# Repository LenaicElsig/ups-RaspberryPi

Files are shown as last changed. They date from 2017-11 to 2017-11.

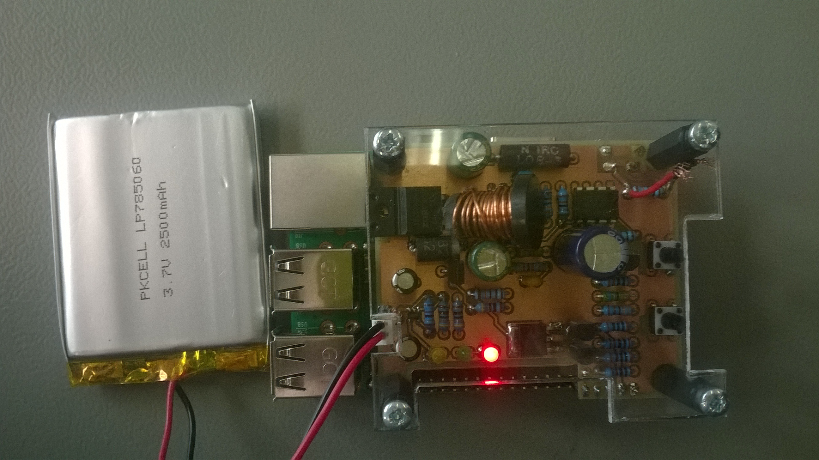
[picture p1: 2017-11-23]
WP_20171013_008.jpg

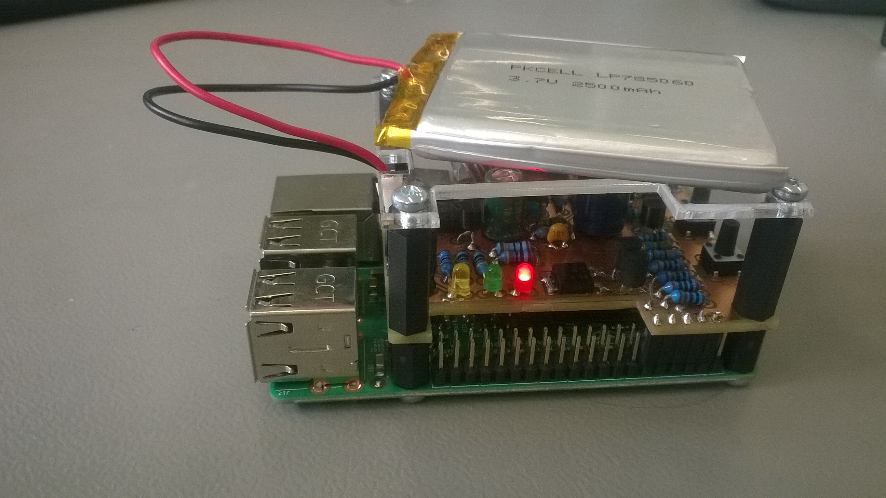
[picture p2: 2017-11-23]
WP_20171013_006.jpg

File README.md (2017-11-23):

# ups-RaspberryPi
Uninterrupted power supply for Raspberry Pi
This project has been developped during a 3-months traineeship in the Hes-so Valais.
The goal was to design a open-source uninterrupted power supply for the Raspberry-Pi, in case of a power failure such
as someone unplugging it. It is made with components easily available online, and can be mounted on a pcb board.
It features : a single cel li-po, a step up 3.7v -> 5v, a battery charger, power indication and reset-shutdown buttons for the Raspberry Pi. It can be directly plugged on the Pi, and only a single power supply is needed.

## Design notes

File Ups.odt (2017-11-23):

Raspberry pi's Ups

## Description :

Durant mon stage de 3 mois à la Hes, on m'a demandé de développer une UPS

(uninterrupted power supply) (source de courant ininterrompue) pour un projet déjà developpé par la Hes , le Raposfly.

Le Raspofly est un projet de caisse enregistreuse commandée par smartphone. Il est ocmposé d'une imprimante thermique , d'un Raspberry pi qui fait serveur web et d'une UPS. L'Ups est là pour fournir du courant au Raspberry Pi au cas où quelqu'un tirerait la prise.

Les contraintes du projet était :

- Doit pouvoir alimenter le Pi en cas de coupure de courant pendant un certain temps
- ne pas prendre trop de place car le système doit être portable
- Être alimentée par une batterie Li-Po

Table des matières

## Schéma bloc :

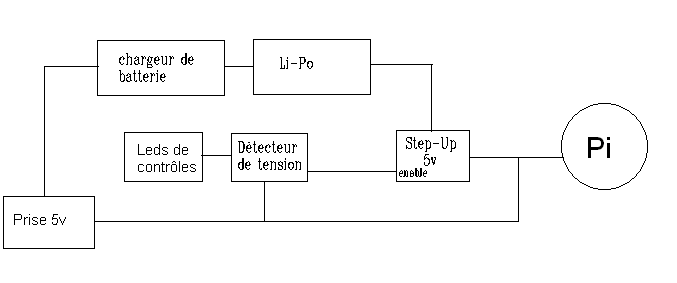
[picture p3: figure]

## Schéma :

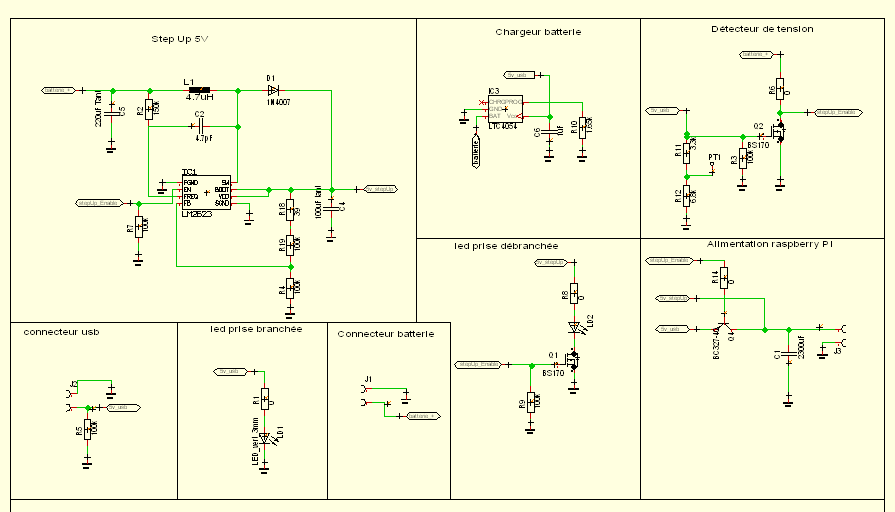
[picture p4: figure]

## Parties du schéma :

Batterie : Pour pouvoir fournir du courant au Pi, j'ai décidé de partir sur une partie Li-Po car :

- Ce sont les types de batteries les plus courantes de nos jours, donc il existe beaucoup de documentation
- Elle ont une bonne densité énergétique/massique ce qui les rend plus petite à capacité égale que les batteries aux Nickel par exemple
- Elle ne coûte pas trop cher et ce trouve presque partout

La batterie sera une batterie 1s ( 3.7v) 750 mah, ce qui devrait être suffisant pour fournir environ 20 minutes de puissance au rasbperry Pi.

Step – up : La batterie Li-Po fournit une tension entre 4.2v et 3.3 v, il faut donc la convertir en une tension de 5vdc utilisable par le Pi. Pour cela j'ai choisi un LM2623 qui est un convertisseur DC/DC boost car il est efficient (plus de 90%), qu'il peut fournir 2A ,qu'il n'est pas trop cher et qu'il est utilisé couramment. Le désavantage des convertisseurs boost par contre est que les dispositions de celui-ci est des composants qui s'y rapportent doivent être précises sur le PCB et la longueur/taille de pistes aussi pour fonctionner. Il dispose aussi d'une fonction enable/disable utile quand on n'a pas besoin du step-up.

chargeur batterie : Ce circuit charge la batterie quand il est branché à une prise. J'ai choisi un LTC4054 car il est simple à utiliser, peut fournir jusqu’à 800mA et a été spécialement conçu pour les batteries Li-Po et les applications portables.

Détecteur de tension : Le détecteur de tension est juste un montage avec transistor mosfet inverseur qui va produire du 5v si la tension à mesurer (la prise) est à 0v. J'ai inclus une résistance de step-down pour être sûr que si la prise est enlevée la tension tombe à 0v. J'ai aussi inclus un pont diviseur 5v→3.3vdc pour permettre de fournir l'information de coupure de courant au GPIOs du Pi qui ne supporte que du 3.3v.

Leds de contrôle : J'ai inclus 2 leds sur ce projet pour informer l'utilisateur d'une coupure de courant (led rouge) mais aussi que tout va bien (led verte) et une led de charge jaune.

## Mesures Step-Up:

J'ai d'abord fait un PCB juste pour le step up, ce qui m'a permis de voir si la disposition des composants était juste et si il fonctionnait. J'ai effectué quelques mesures.

J'ai branché un rhéostat à la sortie du step-up et j'ai mesuré la tension de sortie en fonction du courant demandé.

courant | 100mA | 300mA | 500mA | 1A | 1.5A
tension | 5.15v | 5.12v | 5.11v | 5.07v | 5v

L'on peut remarquer que la tension de sortie est relativement stable par rapport au courant, ce qui est bien parce que le Raspberry Pi ne fonctionne plus si la tension d'alimentation descend en-dessous de 4.8V.

Je n'ai pas testé un courant plus élevé car Imax est 2A et je ne voulais pas stresser le composants inutilement. En outre, il y a peu de chance que le Rapsberry ait besoin de plus de 1.5A.

## Mesures PCB V2.0:

J’ai créé un PCB 1.0. Il n’a pas fonctionnée du premier coup alors j’ai dû le dépanner. J’en ai profité pour faire des améliorations notamment une diode MosFet. J’ai donc créé une version 2.0 du PCB sur laquelle j’ai rajouté les modifications et réparer les pannes.

Mesure tension vs courant sur secteur (VCC = 5V) :

courant | 5mA | 300mA | 500mA | 700mA | 1A | 1.5A
tension | 5.03v | 4.99v | 4.95 | 4.92v | 4.86v | 4.8v

On peut voir que la tension est assez constante par rapport au courant demandé, elle baisse seulement de 200mV pour 1A par rapport à 5mA. Ce sont de bons résultats, ils correspondent à ce que j’attendais.

Mesure tension vs courant batterie :

courant | 5mA | 300mA | 500mA | 700mA | 800mA
tension | 5.05v | 5.04v | 5.04 | 5.04v | 5.04v

On peut voir que le step-up fait très bien son travail car il fournit une tension constante indépendamment du courant.

Mesure de la charge de la batterie :

La batterie charge quand le circuit est branché à 5V, le courant de charge mesure est de 500 mA si Ubatterie = 3.8V. Il diminue progressivement à mesure que la tension de la batterie augmente et il est nul si Ubatterie = 4.2V.

Mesure décharge batterie :

Chaque 2 minutes la tension de la batterie est mesurée. Décharge = 1A.

Temps(minutes) | 0 | 2 | 4 | 6 | 8 | 10
Ubatterie (V) | 3.45 | 3.44 | 3.43 | 3.43 | 3.42 | 3.41

La batterie se décharge lentement ce qui permettra d’alimenter le Pi assez longtemps.

Mesure chute de tension branché débranché :

On peut voir qu'il y a une légère chute de tension à 3.5v pendant un court instant, mais cela n'a pas l'air d'affecter le Raspberry Pi

Mesure chute de tension débranché branché :

On peut voir que la tension passe presque instantanément de 5.2v(la batterie) à 5v (le secteur),

## Impression du PCB:

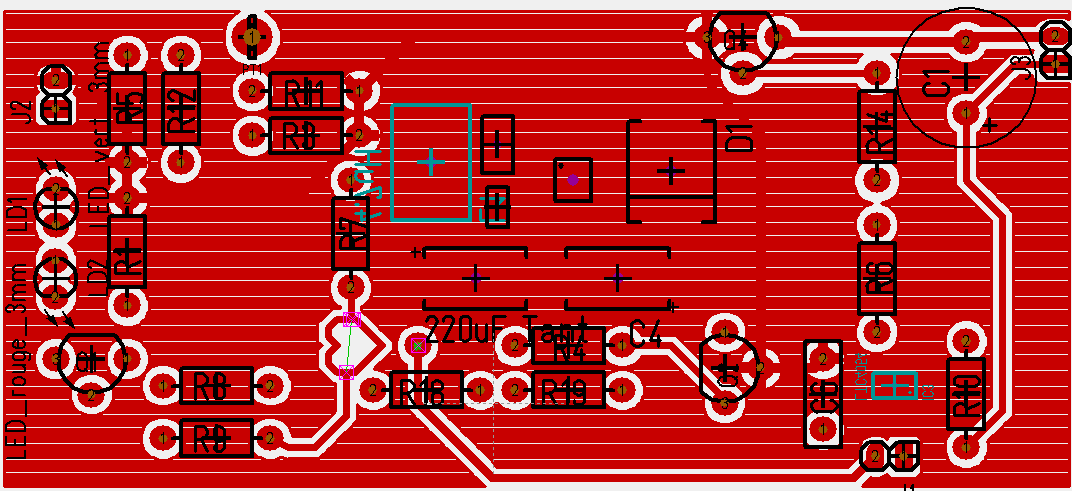
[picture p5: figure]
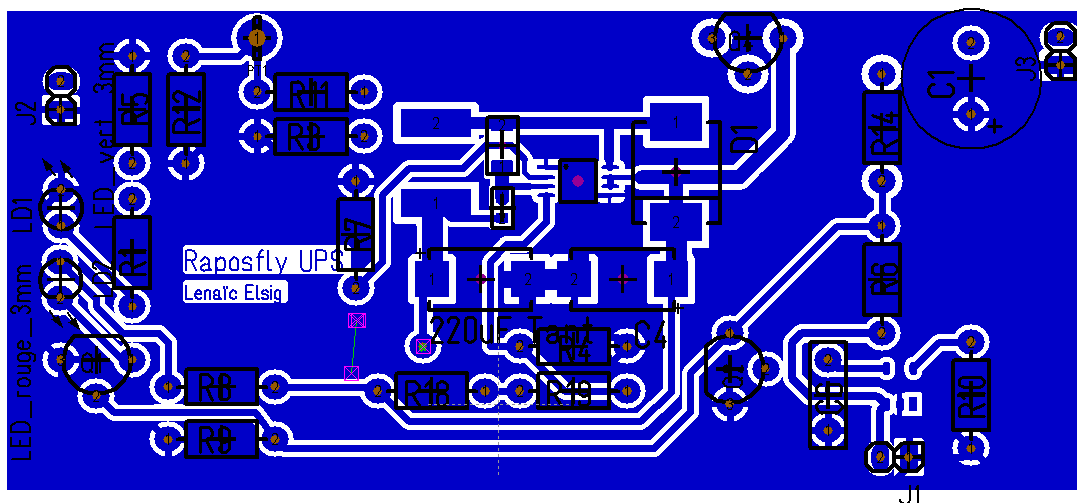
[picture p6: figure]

PCB du step-up :

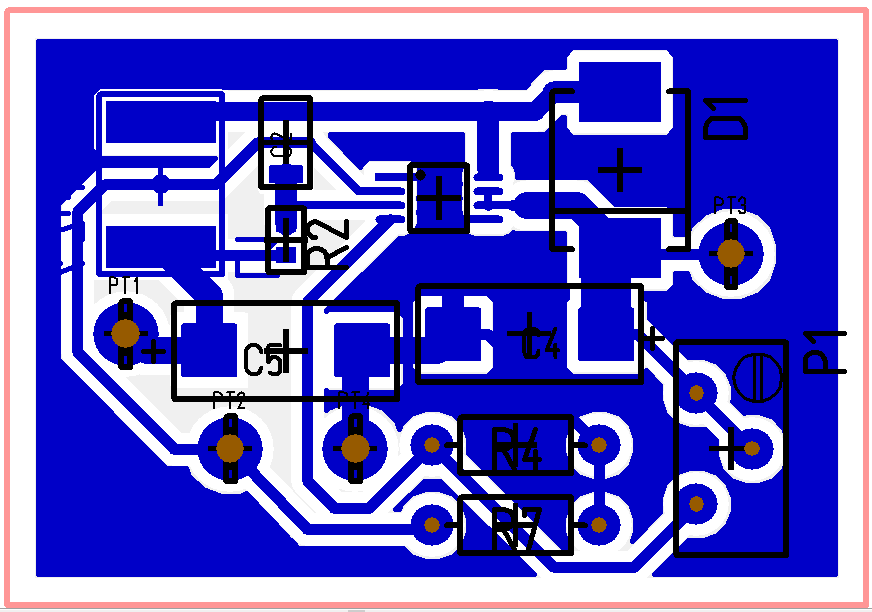
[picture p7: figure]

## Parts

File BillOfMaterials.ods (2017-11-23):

Bills of material
The components below must be the same or some with close characteristics, the datasheet for the max1771 give the important point. |  |  |  | E-shop i used
 |  |  |  | N°Distrelec
Diverse : | 1x | MAX1771 |  | 173-36-068
 | 1x | Battery Charging IC 3.75...6 V/MCP73831T |  | 173-86-933
 | 1x | Inductor, radial 22 uH 5.4 A Low Resistance |  | 158-00-444
 | 1x | Schottky diode 3 A 40 V, any schottky > 2A |  | 170-10-325
 | 2x | Condensateurs électrolytiques aluminium 330 uF 16 VDC Low ESR |  | 167-23-373
The components are the one used, you can use other one that have suitable characteristics, theyll be fine too.
Resistors : | 3x | 470
 | 1x | 2k
 | 3x | 100k
 | 2x | 3.3k
 | 1x | 6.8k
 | 2x | 100
 | 1x | 5.6k
 | 3x | 1k
 | 1x | 33k
 | 1x | 25mili
 | 1x | 82k
Capacitors : | 1x | 2300uF | > 6v
 | 2x | 4.7uF | > 6v
 | 2x | 100nF | > 6v
 | 1x | 100pF | > 6v
Transistors : | 1 x BS170 (Mosfet)
 | 2 x BC327-40
 | 1 x sud50p04 (Mosfet)
 | 2 x BS250 (Mosfet)
 | 1 x IRLIZ44N (Mosfet)
Leds : | 1 x red led
 | 1x green led
 | 1x yellow led
Connectors : | 1 x micro USB B
 | 1 x battery connector(the battery can also be soldered)
 | 5x male headers
battery : | LiPo 1s(3.7v) > 500 mAh
buttons : | 2x push buttons 6x6mm
Op-amp : | 1 x LF351N

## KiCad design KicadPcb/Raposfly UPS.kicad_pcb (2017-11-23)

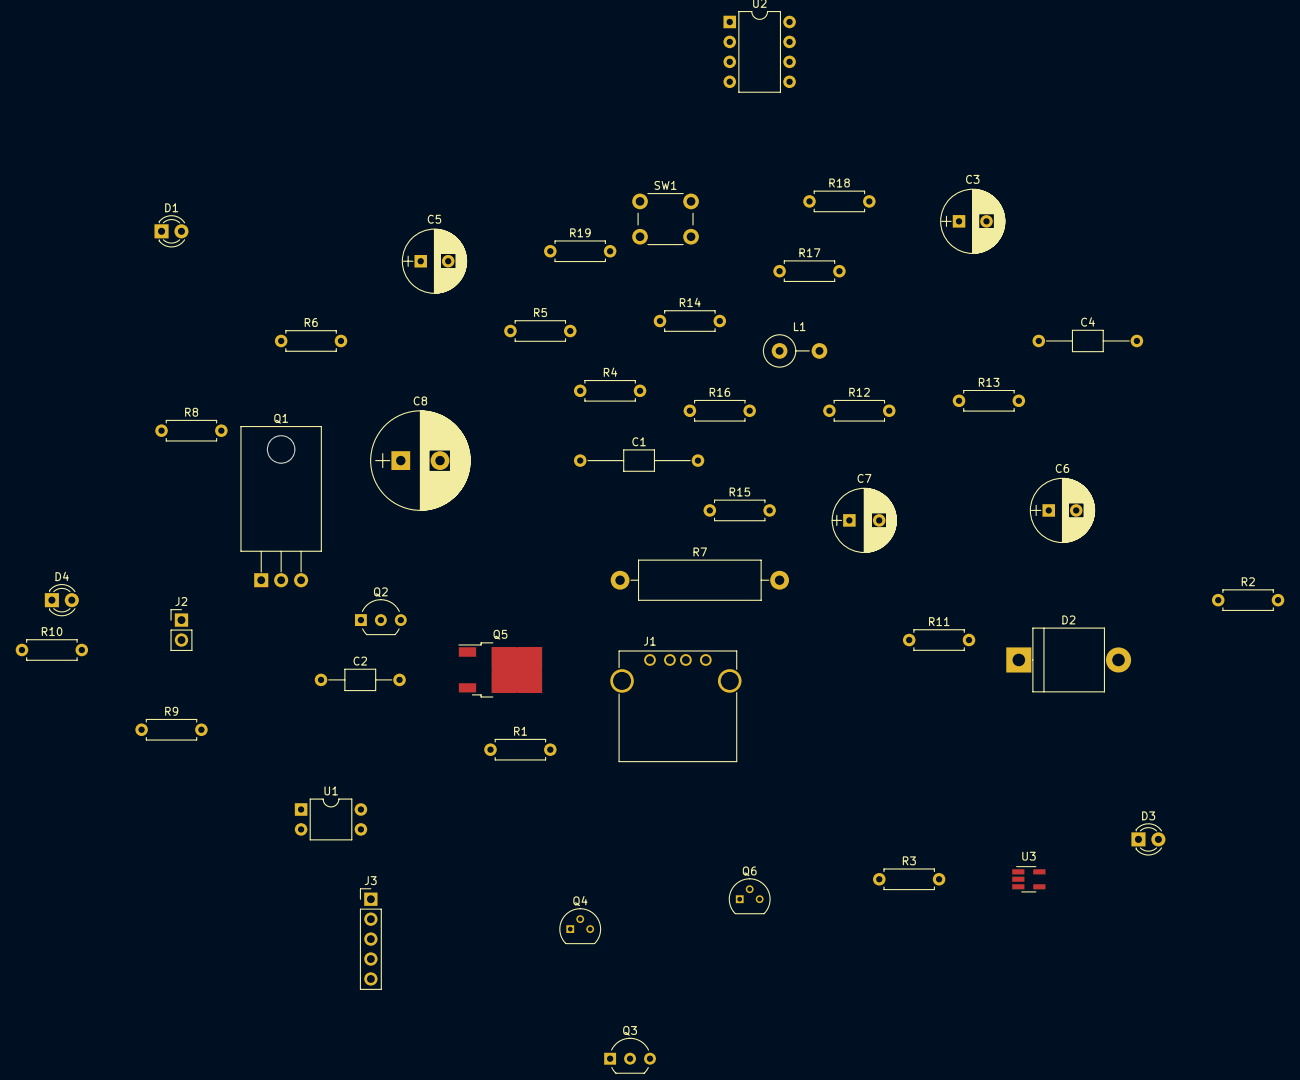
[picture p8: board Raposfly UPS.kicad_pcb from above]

Board: 2 copper layers, 45 parts (0 on the bottom side), 25 nets, no tracks yet.

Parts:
C1: 100nF; C_Axial_L3.8mm_D2.6mm_P15.00mm_Horizontal
C2: 100pF; C_Axial_L3.8mm_D2.6mm_P10.00mm_Horizontal
C3, C5: 330uF; CP_Radial_D8.0mm_P3.50mm
C4: 100nF; C_Axial_L3.8mm_D2.6mm_P12.50mm_Horizontal
C6: 4.7uF; CP_Radial_D8.0mm_P3.50mm
C7: 4.7uF; CP_Radial_D8.0mm_P3.80mm
C8: 2300uF; CP_Radial_D12.5mm_P5.00mm
D1, D3, D4: LED; LED_D3.0mm
D2: 1N5822; D_5KPW_P12.70mm_Horizontal
J1: USB_A
J2: Conn_01x02_Female; Socket_Strip_Straight_1x02_Pitch2.54mm
J3: Conn_01x05_Female; Socket_Strip_Straight_1x05_Pitch2.54mm
L1: 22uH; L_Axial_L9.5mm_D4.0mm_P5.08mm_Vertical_Fastron_SMCC
Q1: IRLIZ44N; TO-220_Horizontal
Q2: bs170; TO-92_Inline_Wide
Q3: bs250; TO-92_Inline_Wide
Q4, Q6: BC327; TO-92_Molded_Narrow
Q5: sud50p04; TO-252-2
R1, R16: 3.3k; R_Axial_DIN0207_L6.3mm_D2.5mm_P7.62mm_Horizontal
R2: 5.6k; R_Axial_DIN0207_L6.3mm_D2.5mm_P7.62mm_Horizontal
R3: 82k; R_Axial_DIN0207_L6.3mm_D2.5mm_P7.62mm_Horizontal
R4, R8, R12: 100k; R_Axial_DIN0207_L6.3mm_D2.5mm_P7.62mm_Horizontal
R5: 33k; R_Axial_DIN0207_L6.3mm_D2.5mm_P7.62mm_Horizontal
R6, R13, R14: 470; R_Axial_DIN0207_L6.3mm_D2.5mm_P7.62mm_Horizontal
R7: 25mili; R_Axial_DIN0516_L15.5mm_D5.0mm_P20.32mm_Horizontal
R9, R10, R18: 1k; R_Axial_DIN0207_L6.3mm_D2.5mm_P7.62mm_Horizontal
R11: 2k; R_Axial_DIN0207_L6.3mm_D2.5mm_P7.62mm_Horizontal
R15, R19: 100; R_Axial_DIN0207_L6.3mm_D2.5mm_P7.62mm_Horizontal
R17: 6.8k; R_Axial_DIN0207_L6.3mm_D2.5mm_P7.62mm_Horizontal
SW1: SW_DPST_x2; SW_PUSH_6mm
U1: LF355; DIP-4_W7.62mm
U2: max1771; DIP-8_W7.62mm
U3: MCP7383; SOT-23-5_HandSoldering

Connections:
/5v_stepUp: C1.1, C2.2, C5.1, C8.1, D2.1, J3.1, Q3.1, Q5.3, Q6.3, R1.1, R3.2, SW1.1, U2.2
/5v_usb: C6.1, D3.2, J1.1, Q3.2, Q4.3, Q5.1, R4.1, R6.1, R12.1, R16.1, U2.4, U3.4
/batterie_+: C3.1, C7.1, J2.2, L1.2, U1.2, U3.3
/gpio14/8: J3.3, R9.2
/gpio15/10: J3.4, R10.2
/gpio18/12: J3.5, R16.2, R17.1
/shutdown: Q2.2, R8.1, SW1.2
GND: C1.2, C3.2, C4.2, C5.2, C6.2, C7.2, C8.2, D1.1, D4.1, J1.4, J2.1, J3.2, Q2.3, R2.2, R4.2, R5.2, R7.2, R8.2, R12.2, R15.2, R17.2, R18.2, R19.2, U1.1, U1.4, U2.6, U2.7
unnamed: C2.1, R3.1, R5.1, U2.3
unnamed: C4.1, U2.5
unnamed: D1.2, R6.2
unnamed: D2.2, L1.1, Q1.1
unnamed: D3.1, R13.1
unnamed: D4.2, R14.2
unnamed: Q1.2, U2.1
unnamed: Q1.3, R7.1, U2.8
unnamed: Q2.1, R9.1
unnamed: Q3.3, R14.1
unnamed: Q4.1, R15.1
unnamed: Q4.2, Q6.2, R18.1
unnamed: Q5.2, Q6.1, R19.1
unnamed: R1.2, R2.1, U1.3
unnamed: R11.1, U3.5
unnamed: R11.2, U3.2
unnamed: R13.2, U3.1

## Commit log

2017-11-23 Added pcb layout for Kicad
    [Raposfly UPS.kicad_pcb, Raposfly UPS.sch]
2017-11-23 Added list of parts
    [BillOfMaterials.ods, BillOfMaterials.xlsx]
